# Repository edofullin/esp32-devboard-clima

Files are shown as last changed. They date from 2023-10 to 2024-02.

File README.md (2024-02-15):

# ESP32-Clima

This repository contains the design and production files that I used to build by own ESP32-based OpenTherm* and ON/OFF thermostats.

The devices is based on a ESP32-S3 microcontroller, and can include *exclusively* a OpenTherm driver circuit or a latching on/off relay to drive the boiler. 
Optionally, a BME280 sensor can be soldered onto the board in order to measure temperature, humidity and pressure (and use them for control).

## Schematic

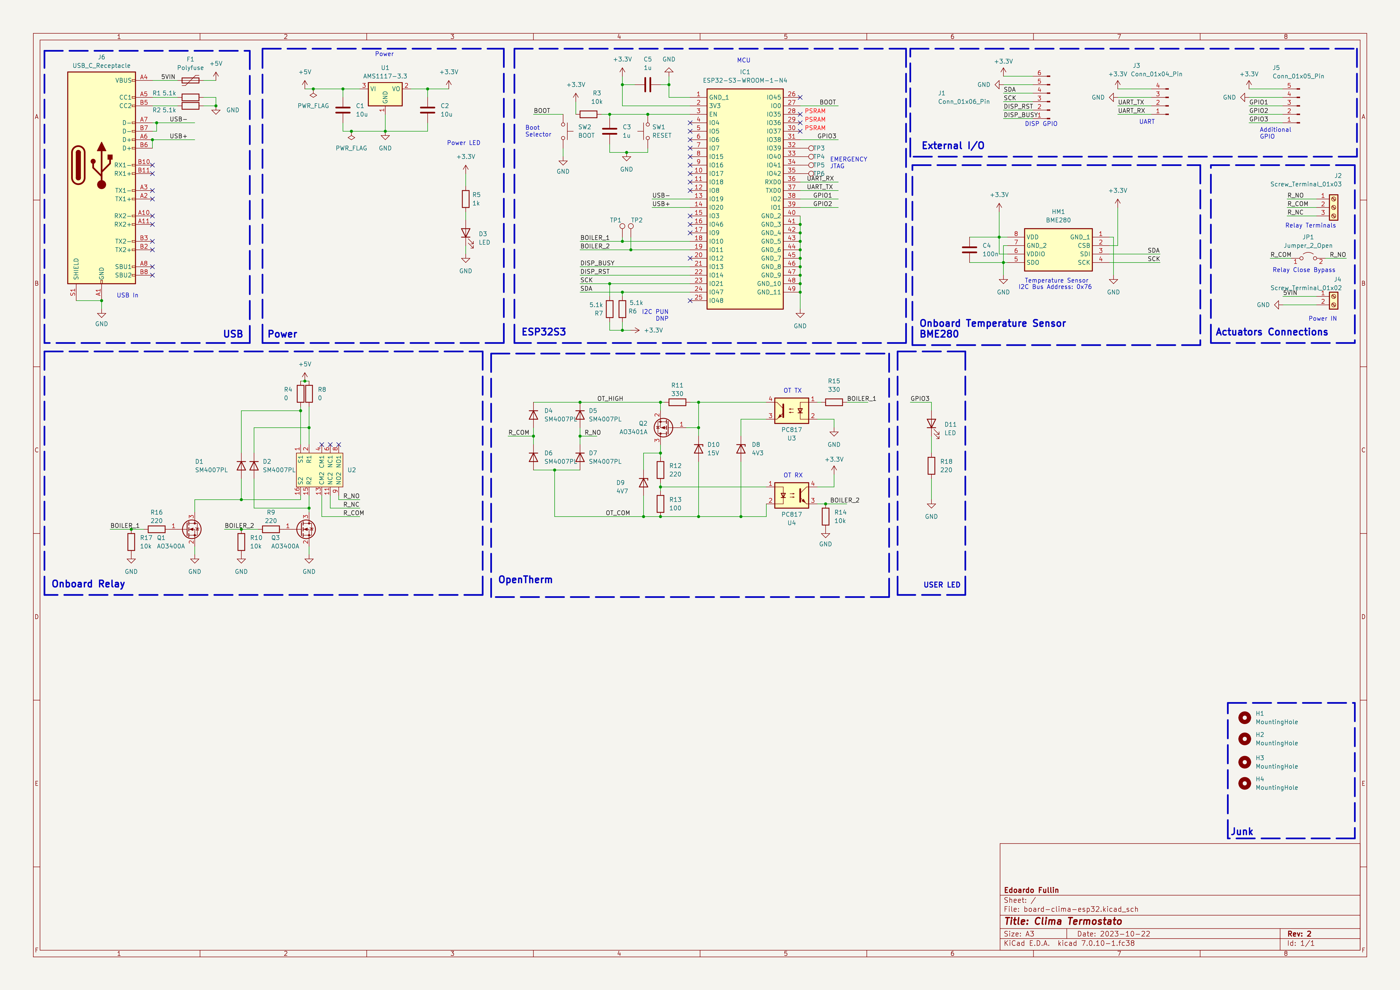
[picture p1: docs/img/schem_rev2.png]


## PCB Design

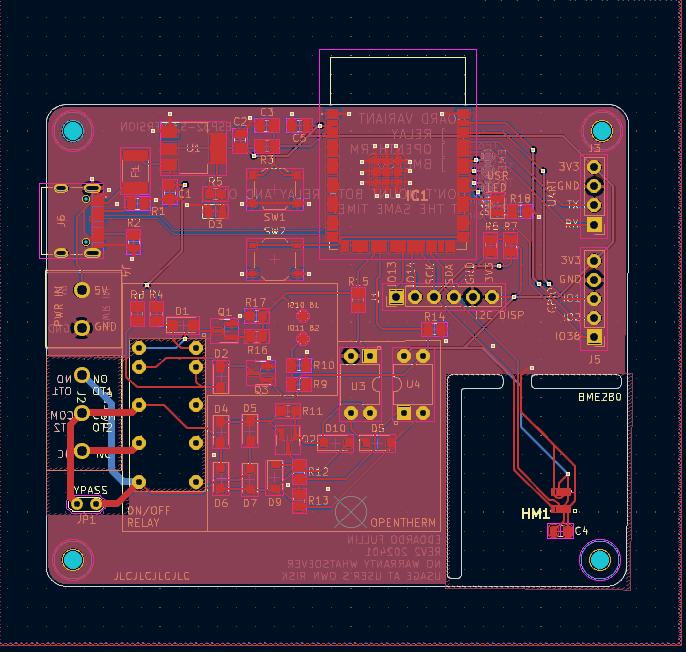
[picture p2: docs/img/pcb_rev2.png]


## Final Result (OpenTherm version, no BME280)

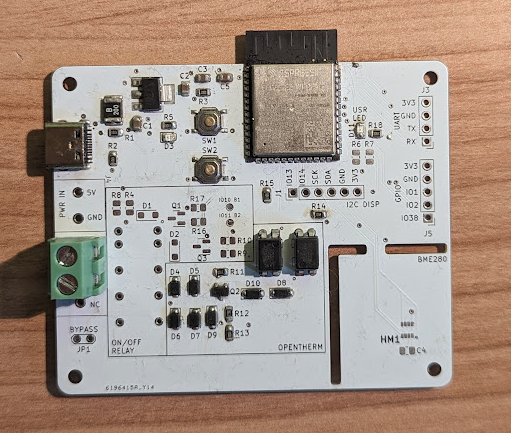
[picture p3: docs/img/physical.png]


Mounted by me by hand, imperfect but functioning. 

## Disclaimers

I'm an not a PCB designer / electronics professional, everything here is provided for free and the user assumes all resposibilities of what they do with the material.
This material comes AS-IS with ABSOLUTELY NO WARRANTY.

*I'm **NOT** affiliated with the [OpenTherm Association](https://www.opentherm.eu/) in any way, the circuit has **only** been tested by me on my own boiler and is not guaranteed to work on every boiler.

The OpenTherm circuit part is heavily inspired by [this](https://electronics.stackexchange.com/questions/466720/how-does-this-circuit-work-opentherm) StackExchange post.

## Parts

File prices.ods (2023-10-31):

 | B1 LSCS | B2 ASS LSCS
PCB | € 1.89 | € 1.89
SETUP | € 7.57
STENCIL | € 1.42
COMPONENTS | € 18.59
EXTENDED COMPONE | € 5.36
OTHER | € 0.95
PCB | € 35.78 | € 1.89
SPED E TASSE | € 18.10 | € 2.12
SCONTO CHECKOUT | -€ 8.62
TOTALE JLCPCB | € 45.26 | € 4.01
ESP32WROOM (5X) | € 18.30 | € 18.30
RELAY (X5) | € 5.00 | € 5.00
POLYFUSE | € 0.47 | € 0.45
SCREW TERMINAL (X5) | € 1.02 | € 1.02
ALTRO LSCS | € 0.00 | € 23.85
SPED E TASSE LSCS | € 10.81 | € 0.00
TOTALE LSCS | € 35.61 | € 48.62
TOTALE | € 80.87 | € 52.63
NBOARD | 5 | 5
TOTALE A BOARD | € 16.17 | € 10.53

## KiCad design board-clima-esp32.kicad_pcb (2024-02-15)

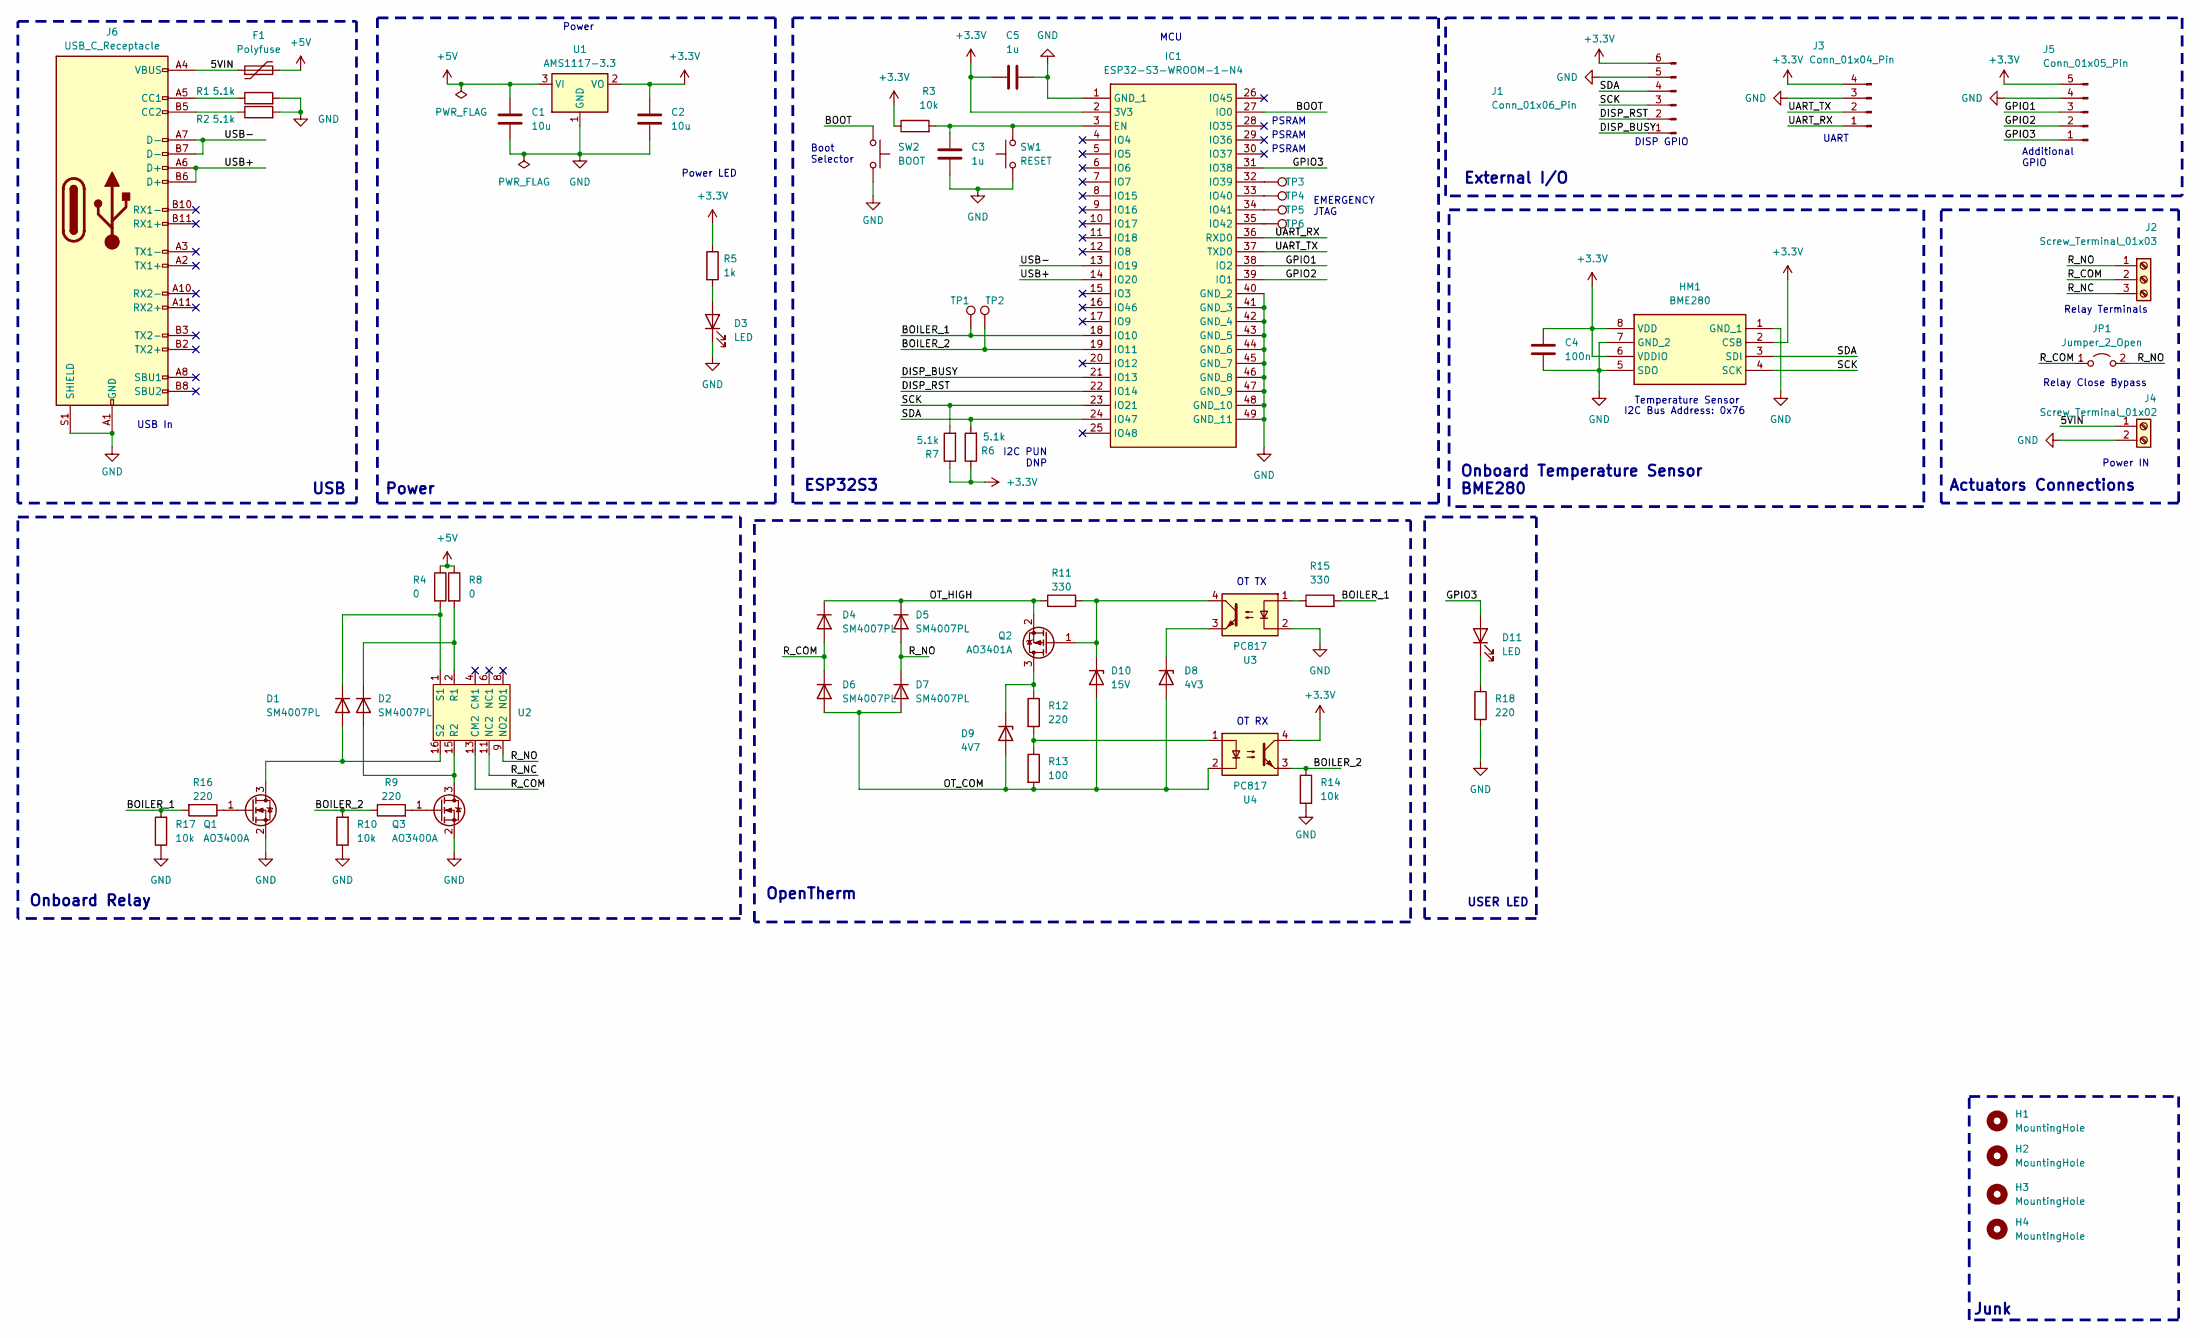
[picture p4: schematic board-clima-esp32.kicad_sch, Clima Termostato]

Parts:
C1, C2: 10u; C_0805_2012Metric; Manufacturer_Part_Number CL21A106KAYNNNE; LCSC C15850
C3: 1u; C_0805_2012Metric; Manufacturer_Part_Number CL21B105KBFNNNE; LCSC C28323
C4: 100n; C_0805_2012Metric; Manufacturer_Part_Number CC0805KRX7R9BB104; LCSC C49678
C5: 1u; C_0805_2012Metric
D1, D2, D4, D5, D6, D7: SM4007PL; D_SOD-123F
D3: LED; LED_0805_2012Metric; Manufacturer_Part_Number NCD0805R1; LCSC C84256
D8: 4V3; D_SOD-123
D9: 4V7; D_SOD-123
D10: 15V; D_SOD-123
D11: LED; LED_0805_2012Metric
F1: Polyfuse; Fuse_1812_4532Metric_Pad1.30x3.40mm_HandSolder; Manufacturer_Part_Number BSMD1812-200-30V; LCSC C960026
H1, H2, H3, H4: MountingHole; MountingHole_2.5mm
HM1: BME280; Mouser Part Number 262-BME280
IC1: ESP32-S3-WROOM-1-N4; ESP32S3WROOM1N8R8; Mouser Part Number 356-EP32S3WROOM1N8R8
J1: Conn_01x06_Pin; PinHeader_1x06_P2.54mm_Vertical
J2: Screw_Terminal_01x03; XYEK500-5.08-3P; Manufacturer_Part_Number XYEK500-5.08-3P
J3: Conn_01x04_Pin; PinHeader_1x04_P2.54mm_Vertical
J4: Screw_Terminal_01x02; XYEK500-5.08-2P
J5: Conn_01x05_Pin; PinHeader_1x05_P2.54mm_Vertical
J6: USB_C_Receptacle; HRO_TYPE-C-31-M-12; Manufacturer_Part_Number TYPE-C-31-M-12; LCSC C165948
JP1: Jumper_2_Open; TestPoint_2Pads_Pitch2.54mm_Drill0.8mm
Q1, Q3: AO3400A; SOT-23
Q2: AO3401A; SOT-23
R1, R2, R6, R7: 5.1k; R_0805_2012Metric; Manufacturer_Part_Number 0805W8F5101T5E; LCSC C17673
R3: 10k; R_0805_2012Metric; Manufacturer_Part_Number 0805W8F1002T5E; LCSC C17414
R4, R8: 0; R_0805_2012Metric
R5: 1k; R_0805_2012Metric; Manufacturer_Part_Number 0805W8F2200T5E; LCSC C17557
R9, R12, R16, R18: 220; R_0805_2012Metric
R10, R14, R17: 10k; R_0805_2012Metric
R11, R15: 330; R_0805_2012Metric
R13: 100; R_0805_2012Metric
SW1: RESET; SW_Push_1P1T_XKB_TS-1187A; Manufacturer_Part_Number TS-1187A-B-A-B; LCSC C318884
SW2: BOOT; SW_Push_1P1T_XKB_TS-1187A; Manufacturer_Part_Number TS-1187A-B-A-B; LCSC C318884
TP1, TP2, TP3, TP4, TP5, TP6: TestPoint; TestPoint_Pad_D1.0mm
U1: AMS1117-3.3; SOT-223-3_TabPin2; Manufacturer_Part_Number 0805W8F5101T5E; LCSC C6186
U2: HFD2-00X-M-L2
U3, U4: PC817; DIP-4_W7.62mm

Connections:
+3.3V: C2.1, C4.1, C5.1, HM1.2 (CSB), HM1.6 (VDDIO), HM1.8 (VDD), IC1.2 (3V3), J1.6, J3.4, J5.5, R3.1, R5.1, R6.1, R7.1, U1.2 (VO), U4.4
+5V: C1.1, F1.2, R4.1, R8.1, U1.3 (VI)
/5VIN: F1.1, J4.1, J6.A4 (VBUS), J6.A9 (VBUS), J6.B4 (VBUS), J6.B9 (VBUS)
/BOILER_1: IC1.18 (IO10), R15.2, R16.2, R17.2, TP1.1; also elsewhere on the board
/BOILER_2: IC1.19 (IO11), R9.1, R10.2, R14.1, TP2.1, U4.3; also elsewhere on the board
/BOOT: IC1.27 (IO0), SW2.1
/DISP_BUSY: IC1.21 (IO13), J1.1
/DISP_RST: IC1.22 (IO14), J1.2
/GPIO1: IC1.38 (IO2), J5.3
/GPIO2: IC1.39 (IO1), J5.2
/GPIO3: D11.2 (A), IC1.31 (IO38), J5.1
/OT_COM: D6.2 (A), D7.2 (A), D8.2 (A), D9.2 (A), D10.2 (A), R13.2, U4.2
/OT_HIGH: D4.1 (K), D5.1 (K), Q2.2 (S), R11.1
/R_COM: D4.2 (A), D6.1 (K), J2.2, JP1.1 (A), U2.13 (CM2)
/R_NC: J2.3, U2.11 (NC2)
/R_NO: D5.2 (A), D7.1 (K), J2.1, JP1.2 (B), U2.9 (NO2)
/SCK: HM1.4 (SCK), IC1.23 (IO21), J1.3, R7.2
/SDA: HM1.3 (SDI), IC1.24 (IO47), J1.4, R6.2
/UART_RX: IC1.36 (RXD0), J3.1
/UART_TX: IC1.37 (TXD0), J3.2
/USB+: IC1.14 (IO20), J6.A6 (D+), J6.B6 (D+)
/USB-: IC1.13 (IO19), J6.A7 (D-), J6.B7 (D-)
GND: C1.2, C2.2, C3.2, C4.2, C5.2, D3.1 (K), HM1.1 (GND_1), HM1.5 (SDO), HM1.7 (GND_2), IC1.1 (GND_1), IC1.40 (GND_2), IC1.41 (GND_3), IC1.42 (GND_4), IC1.43 (GND_5), IC1.44 (GND_6), IC1.45 (GND_7), IC1.46 (GND_8), IC1.47 (GND_9), IC1.48 (GND_10), IC1.49 (GND_11), J1.5, J3.3, J4.2, J5.4, J6.A1 (GND), J6.A12 (GND), J6.B1 (GND), J6.B12 (GND), J6.S1 (SHIELD), Q1.2 (S), Q3.2 (S), R1.2, R2.2, R10.1, R14.2, R17.1, R18.2, SW1.1, SW2.2, U1.1 (GND), U3.2
unnamed: D1.2 (A), Q1.3 (D), U2.16 (S2)
unnamed: D1.1 (K), R4.2, U2.1 (S1)
unnamed: D2.2 (A), Q3.3 (D), U2.15 (R2)
unnamed: D2.1 (K), R8.2, U2.2 (R1)
unnamed: D3.2 (A), R5.2
unnamed: D8.1 (K), U3.3
unnamed: D9.1 (K), Q2.3 (D), R12.1
unnamed: D10.1 (K), Q2.1 (G), R11.2, U3.4
unnamed: D11.1 (K), R18.1
unnamed: C3.1, IC1.3 (EN), R3.2, SW1.2
unnamed: IC1.32 (IO39), TP3.1
unnamed: IC1.33 (IO40), TP4.1
unnamed: IC1.34 (IO41), TP5.1
unnamed: IC1.35 (IO42), TP6.1
unnamed: J6.A5 (CC1), R1.1
unnamed: J6.B5 (CC2), R2.1
unnamed: Q1.1 (G), R16.1
unnamed: Q3.1 (G), R9.2
unnamed: R12.2, R13.1, U4.1
unnamed: R15.1, U3.1

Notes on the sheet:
OpenTherm
ESP32S3
MCU
Junk
Onboard Temperature Sensor BME280
Actuators Connections
I2C PUN DNP
PSRAM
Power IN
UART
Relay Close Bypass
Additional GPIO
EMERGENCY JTAG
Boot Selector
External I/O
USER LED
Power
Onboard Relay
OT TX
Temperature Sensor
USB
DISP GPIO
USB In
OT RX
I2C Bus Address: 0x76
Relay Terminals
Power LED

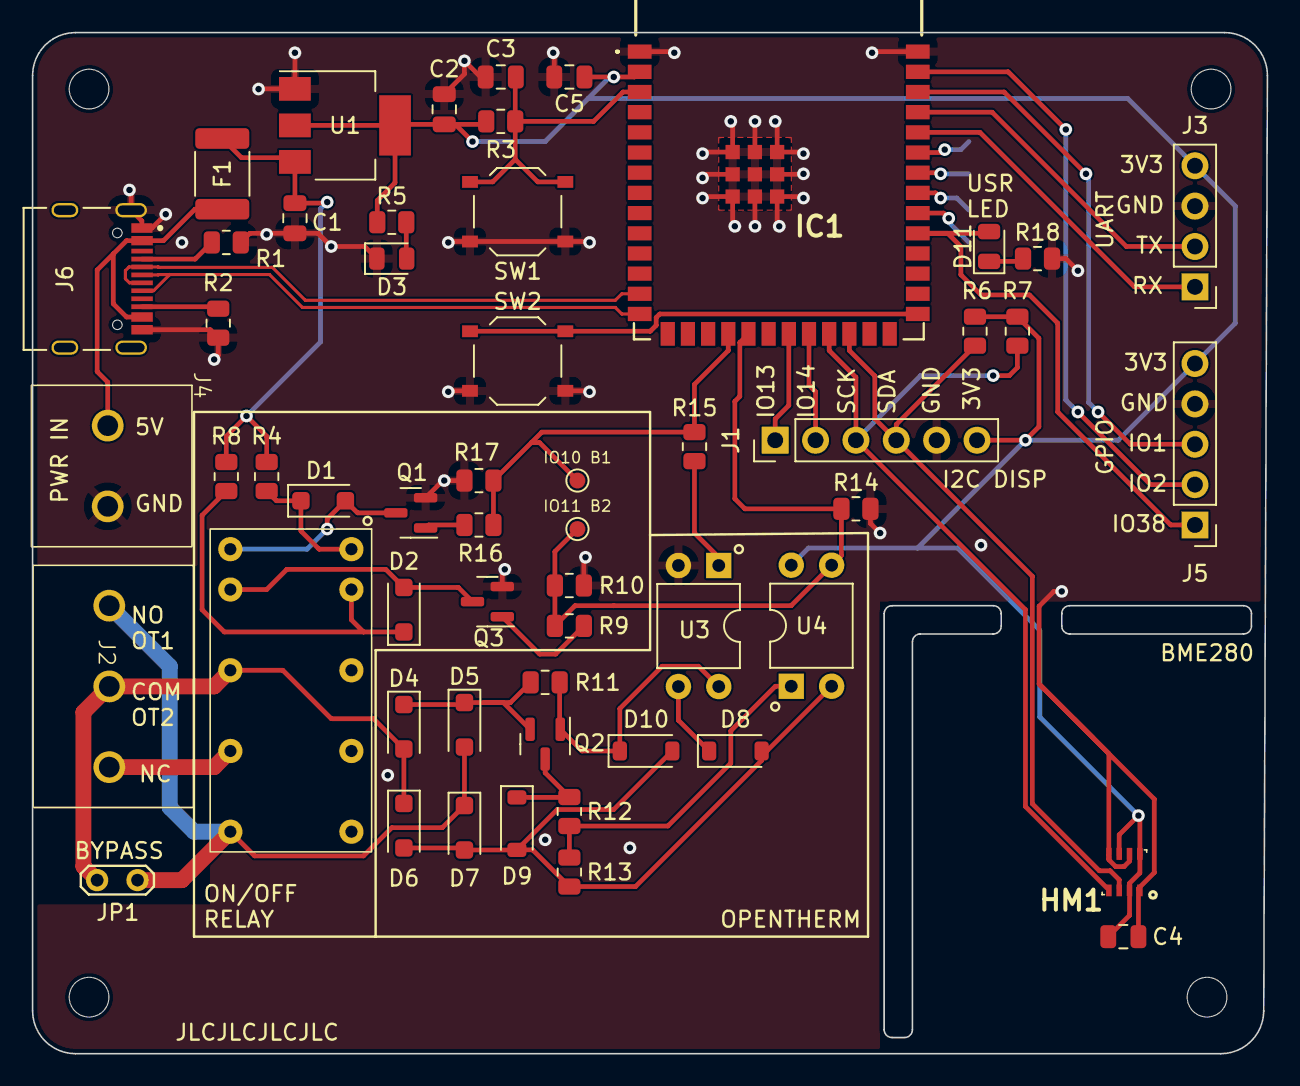
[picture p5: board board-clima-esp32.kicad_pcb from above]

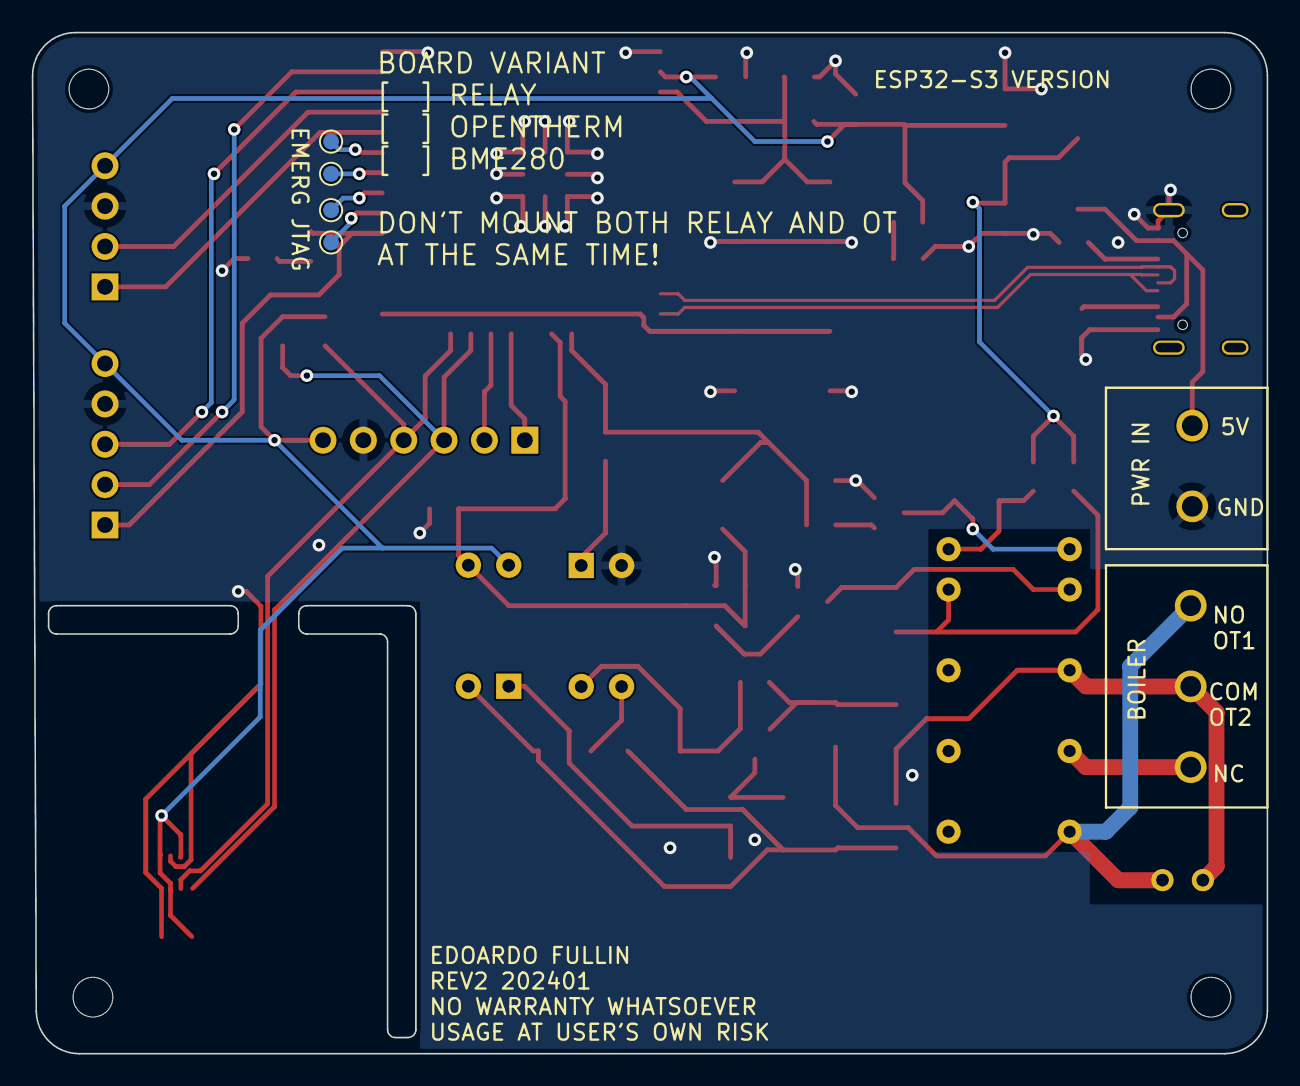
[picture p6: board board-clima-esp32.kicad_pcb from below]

Board: 2 copper layers, 77.7 x 64.3 mm, 63 parts (4 on the bottom side), 43 nets.

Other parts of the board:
IO10 B1, IO11 B2: TestPoint; TestPoint_Pad_D1.0mm

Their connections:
/BOILER_1: IO10 B1.1; also elsewhere on the board
/BOILER_2: IO11 B2.1; also elsewhere on the board

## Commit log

2023-10-22 libs, basic power
    [board-clima-esp32.kicad_pcb, board-clima-esp32.kicad_sch]
2023-10-24 sensor, relay sym footprint
    [board-clima-esp32.kicad_sch]
2023-10-24 schematic ok
    [board-clima-esp32.kicad_sch]
2023-10-24 fucking via clearences
    [board-clima-esp32.kicad_pcb, board-clima-esp32.kicad_sch]
2023-10-25 usb pads, via sizes
    [board-clima-esp32.kicad_pcb]
2023-10-25 moved bme280
    [board-clima-esp32.kicad_pcb]
2023-10-25 should be done
    [board-clima-esp32.kicad_pcb, board-clima-esp32.kicad_sch]
2023-10-27 editing stuff again
    [board-clima-esp32.kicad_pcb, board-clima-esp32.kicad_sch]
2023-10-28 edit to get jlc assembly
    [board-clima-esp32.kicad_pcb, board-clima-esp32.kicad_sch]
2023-10-29 component edits, terminalblock footprint
    [board-clima-esp32.kicad_pcb, board-clima-esp32.kicad_sch, prices.ods]
2023-10-29 was about to fuck everything up
    [board-clima-esp32.kicad_pcb]
2023-10-29 cleanup and some helper in schematic
    [board-clima-esp32.kicad_pcb, board-clima-esp32.kicad_sch]
2023-10-31 added bypass jumper
    [board-clima-esp32.kicad_pcb, board-clima-esp32.kicad_sch, prices.ods]
2023-12-10 refactor schematic
    [board-clima-esp32.kicad_sch]
2023-12-12 spice for opentherm, schematics mod
2023-12-27 OT schematic, relay spice
    [board-clima-esp32.kicad_sch]
2023-12-28 rev2 schematic
    [board-clima-esp32.kicad_sch]
2023-12-29 pcb rev2 placement
    [board-clima-esp32.kicad_pcb, board-clima-esp32.kicad_sch]
2023-12-29 New J1 connector location
    [board-clima-esp32.kicad_pcb, board-clima-esp32.kicad_sch]
2023-12-29 Cleanup pcb layout for easier routing
    [board-clima-esp32.kicad_pcb, board-clima-esp32.kicad_sch]
2023-12-29 rev2 routing
    [board-clima-esp32.kicad_pcb, board-clima-esp32.kicad_sch]
2023-12-29 Moved BME and DISP connector
    [board-clima-esp32.kicad_pcb]
2023-12-30 drc passes
    [board-clima-esp32.kicad_pcb, board-clima-esp32.kicad_sch]
2024-01-03 new PWR connector, front copper pour
    [board-clima-esp32.kicad_pcb, board-clima-esp32.kicad_sch]
2024-01-10 final corrections
    [board-clima-esp32.kicad_pcb, board-clima-esp32.kicad_sch]
2024-01-10 drc pass
    [board-clima-esp32.kicad_pcb, board-clima-esp32.kicad_sch]
2024-01-10 flipped relay
    [board-clima-esp32.kicad_pcb]
2024-02-15 relay was flipped :(
    [board-clima-esp32.kicad_pcb]
